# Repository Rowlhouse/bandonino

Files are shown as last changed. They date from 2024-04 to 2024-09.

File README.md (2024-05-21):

# Bandonino
Teensy powered midi "bandoneon", using mechanical key switches and a load-cell for bellows emulation.

It's powered, and outputs MIDI, over USB. I use my Android phone, running Audio Evolution Mobile, which does low latency MIDI conversion for real-time playing, as well as recording etc.

The bellows emulation uses a 3KG load cell, mounted using rubber grommets to allow for a little bit of movement (1cm or so).

Left/right sides emit midi on different channels so that they can be processed separately. It also outputs a third channel for a metronome.

# Goals

1. To help me learn the keyboard layout
2. To confirm my choice of layout (unisonoric - Peguri/Manoury layout)
3. To provide a learning experience that is at least somewhat "musically satisfying", in order to help me wait for the real thing to arrive.
4. To be a genuine, expressive, musical instrument, that goes beyond "press button, make sound", that might be interesting to use in situations where a real bandoneon isn't appropriate.

# Building 

More complete notes will follow, but for now, the layouts for the key switches are in the Construction directory.

The wiring is "inspired" by the KOOPInstruments projects - e.g. https://www.koopinstruments.com/instrument-projects/melodicade-mx so it uses a matrix (per side) of rows and columns of switches and diodes. Columns are activated in turn, and the buttons from each row are then read.

Most of the build was "improvised" (with 3mm and 6mm plywood sheets), once I'd designed the keyboard layout. The photos below document most of the process.

I was aiming for a "full size" instrument, though with angled ends so it didn't need to be as wide. I also wanted it to have some weight, so it would "open" the bellows to some degree automatically. It could be built much smaller and lighter.

The switches are mounted on plywood, with holes drilled in to (a) position them and (b) let the wires through. Then the matrix is made on the other side by soldering in a million diodes and little wire joiners.

The buttons are 3D printed, with graduated heights. Each button has a little flange. The buttons pass through holes in 2mm fibreglass plate (make the holes 1mm bigger than the buttons!). Now the plate has its height set so that it partially depresses the buttons. This reduces the travel needed to activate each one. 

## Note

If building again I would make two changes:

1. Reduce the button diameter by 0.5mm. This would have two benefits:
    1. increase the spacing between the holes in the plates (I used 2mm fibreglass), and reduce the risk of them breaking into each other.
    2. Make it possible to drill the holes in the plates with a standard size drill bit. 
2. Get a definitive layout from a friendly maker! I used photos to be as accurate as possible, but I think a few buttons are a few mm out.

# Electronics

The main items used are (the links aren't endorsements - just what I used/for reference!)

Teensy 4.1<br>
https://www.amazon.co.uk/dp/B0BHFBY68Q?psc=1&ref=ppx_yo2ov_dt_b_product_details

Gateron KS-9 RGB Mechanical MX Type Key Switch - Clear top (120 Pcs, Red)<br>
https://www.amazon.co.uk/gp/product/B07X3T14CV/ref=ppx_od_dt_b_asin_title_s00?ie=UTF8&psc=1<br>
Note that these need to have the 1mm plastic lugs removed from the sides as they have to be placed very close to each other!

Waveshare 1.5inch OLED Display Module 128x128 Pixels 16-bit Grey Level<br>
https://www.amazon.co.uk/dp/B079NNZ9V1?psc=1&ref=ppx_yo2ov_dt_b_product_details

Stemedu Load Cell 3KG Amplifier HX711<br>
https://www.amazon.co.uk/dp/B07L82YWPV?psc=1&ref=ppx_yo2ov_dt_b_product_details<br>
You need to switch (with delicate soldering!) the amp to use the 80Hz mode. I broke mine so used this load cell with a different HX711 amplifier:
https://www.amazon.co.uk/dp/B081JMSMXV

1N4148 Diodes<br>
https://www.amazon.co.uk/dp/B08TYC1ZRB?psc=1&ref=ppx_yo2ov_dt_b_product_details

KY-040 360 Degree Rotary Encoder<br>
https://www.amazon.co.uk/dp/B07B68H6R8?psc=1&ref=ppx_yo2ov_dt_b_product_details

# Inputs

| Input | Teensy Pin | Notes |
| ----- | --- | ----- |
| Left col 0 | 0 | |
| Left col 1 | 2 | |
| Left col 2 | 3 | |
| Left col 3 | 4 | |
| Left col 4 | 5 | |
| |  |  |
| Right col 0 | 6 | |
| Right col 1 | 7 | |
| Right col 2 | 8 | |
| Right col 3 | 9 | |
| Right col 4 | 20 | |
| Right col 6 | 21 | |
| |  |  |
| Left row 0 | 32 | |
| Left row 1 | 31 | |
| Left row 2 | 30 | |
| Left row 3 | 29 | |
| Left row 4 | 28 | |
| Left row 5 | 27 | |
| Left row 6 | 26 | |
| Left row 7 | 25 | |
| |  |  |
| Right row 0 | 33 | |
| Right row 1 | 34 | |
| Right row 2 | 35 | |
| Right row 3 | 36 | |
| Right row 4 | 37 | |
| Right row 5 | 38 | |
| Right row 6 | 39 | |
| Right row 7 | 40 | |
| Right row 8 | 41 | |
| |  |  |
| Load cell DT or DO/RX | 15 (A1) | From the strain guage to HX711 |
| Load cell SCK or CK/TX | 16 (A2) | red->out+, white->A- green->A+ black->GND |
| Load cell VCC | 5V | 5V seemed more reliable than 3.3 |
| |  |  |
| Rot encoder CLK | 22 | |
| Rot encoder DT | 23 (A9) | |
| Rot encoder SW | 17 | |
| Rot encoder + | 3.3V | |
| |  |  |
| OLED I2C CLK | 19 (SCL) | Set jumpers BS1 = BS2 = 1 to enable I2C |
| OLED I2C DIN | 18 (SDA) | |
| OLED I2C VCC | 3.3V | |

Experiments with a BME280 pressure sensor:
| BME280 CS | 10 | Using SPI |
| BME280 MISO | 12 | |
| BME280 SCK | 13 | |
| BME280 MOSI | 11 | |

# Software

I used a 128x128 display so that the menu system could include live note display - the left/right hands display on bass/treble clefs, or can be displayed as stacked notes. This has been really useful as I learn, and I'm pleased to say is becoming less useful as I improve!

The menu system itself is not written to be a standalone system, but could easily be adapted into a different project.

The main loop runs at a solid 80Hz, keeping up with the load cell/amplifier. When using note display, updating the display as notes change can drop a frame or so, but this is inaudible.

It supports writing/reading all the settings to an SD card - they can be saved explicitly, but also the current setting is saved automatically, and then restored when powering on.

# Libraries/building

I used/you'll need:

* https://www.mathertel.de/Arduino/RotaryEncoderLibrary.aspx
* https://github.com/bogde/HX711
* https://github.com/adafruit/Adafruit_SSD1327 v 1.0.4
* https://arduinojson.org/

I think all of these are available through Aruino Sketch. The full list of libraries is:

    RotaryEncoder at version 1.5.3 : [...]\Documents\Arduino\libraries\RotaryEncoder
    HX711 Arduino Library at version 0.7.5 : [...]\Documents\Arduino\libraries\HX711_Arduino_Library
    Adafruit SSD1327 at version 1.0.4 : [...]\Documents\Arduino\libraries\Adafruit_SSD1327
    Adafruit GFX Library at version 1.11.9 : [...]\Documents\Arduino\libraries\Adafruit_GFX_Library
    Adafruit BusIO at version 1.15.0 : [...]\Documents\Arduino\libraries\Adafruit_BusIO
    Wire at version 1.0 : [...]\AppData\Local\Arduino15\packages\teensy\hardware\avr\1.59.0\libraries\Wire
    SPI at version 1.0 : [...]\AppData\Local\Arduino15\packages\teensy\hardware\avr\1.59.0\libraries\SPI
    ArduinoJson at version 7.0.4 : [...]\Documents\Arduino\libraries\ArduinoJson
    SD at version 2.0.0 : [...]\AppData\Local\Arduino15\packages\teensy\hardware\avr\1.59.0\libraries\SD
    SdFat at version 2.1.2 : [...]\AppData\Local\Arduino15\packages\teensy\hardware\avr\1.59.0\libraries\SdFat

You'll need to select the board as Teensy 4.1 in Arduino Sketch, and USB type is Serial + MIDI

# Videos/photos

## Playing video demo

After learning to play for four weeks: https://youtu.be/XA5RVsj3e9U?si=FQ6Nt5ClDMPxDO7N

The audio is recorded on my phone as midi, and mixed there (so this is exactly what I hear if I play with headphones).

I've decided that the bellows emulation is reasonably effective (or at least, not totally misleading!) when "opening" the bellow - using instrument/arm weight, and modulating these without actively pulling. 

I don't think it emulates "closing" the bellows very well, so I've settled on only playing opening the bellows. This isn't ideal - but I think for proper bandoneon bellows technique, real bellows are needed!

## System demos

Newer:
https://youtu.be/Qa_-vbLSPUA?si=eyVYrDUC1PoKSc3D

Older:
https://youtu.be/M0wQ6heuBrk?si=m23eztmR4TV7uDbV

## Build photos etc

https://photos.app.goo.gl/t3dRVAY1abLQWBCG9

## Smaller set of photos/videos

https://photos.app.goo.gl/e3H986FrXZXdoZyL7

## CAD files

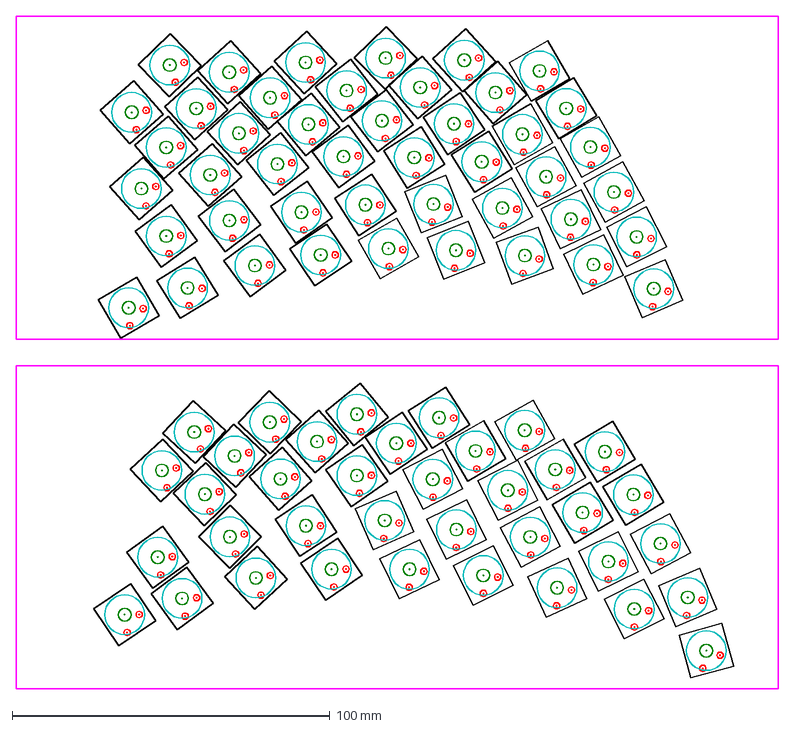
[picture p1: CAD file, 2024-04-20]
Construction/SwitchPlates.dxf
240.0 x 211.8 mm

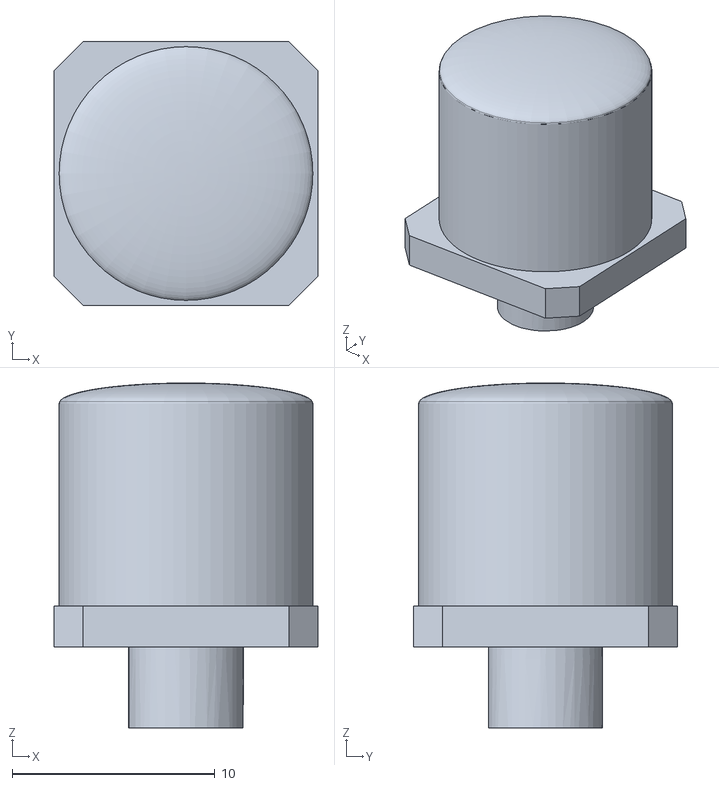
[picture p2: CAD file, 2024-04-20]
Construction/Bando Buttons (5).stl
13.0 x 13.0 x 17.0

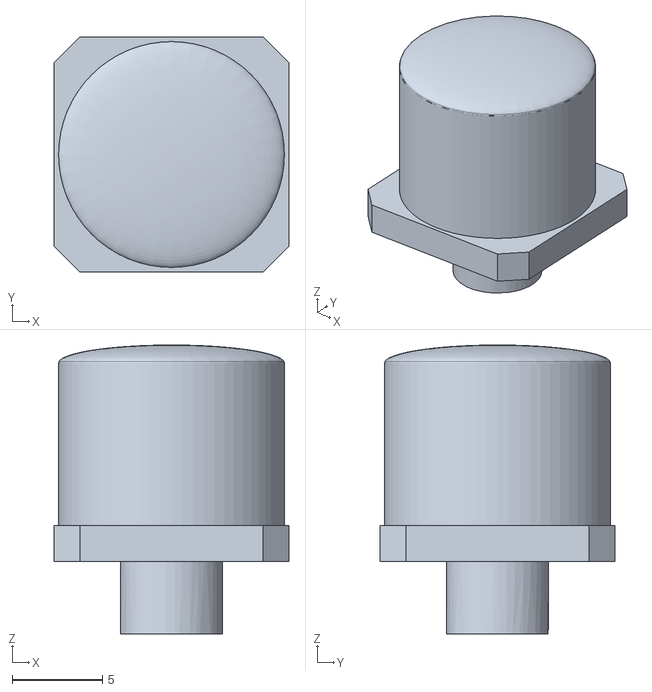
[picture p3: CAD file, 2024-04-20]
Construction/Bando Buttons (4).stl
13.0 x 13.0 x 16.0

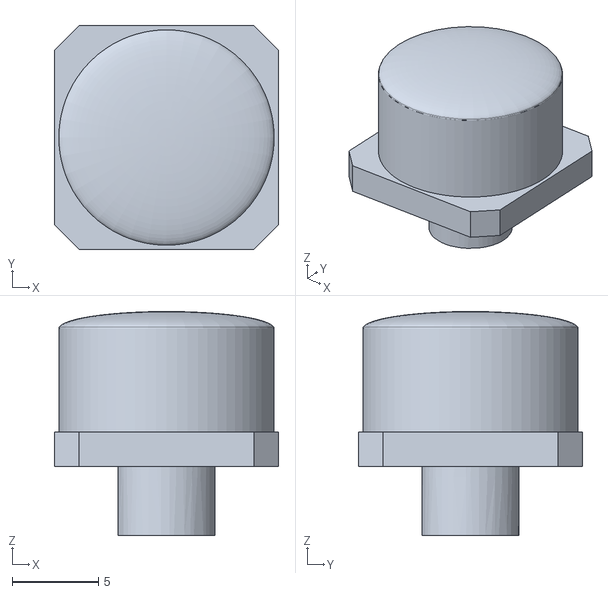
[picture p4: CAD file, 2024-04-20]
Construction/Bando Buttons (1).stl
13.0 x 13.0 x 13.0

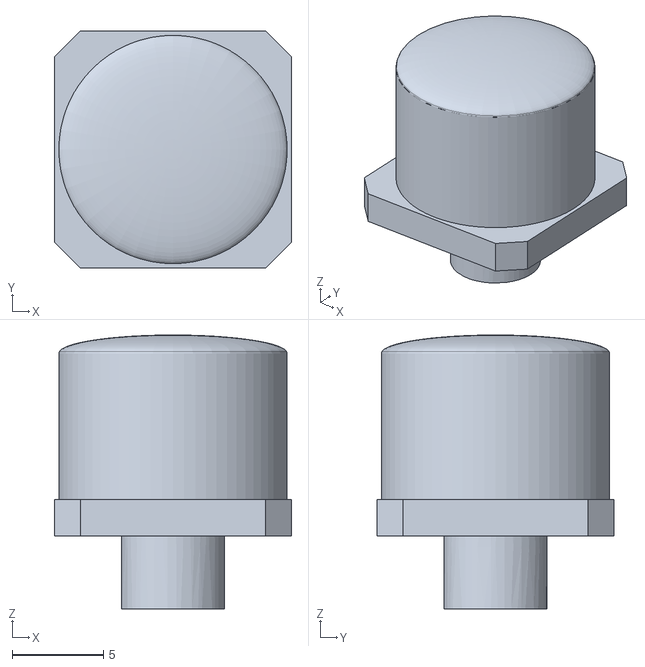
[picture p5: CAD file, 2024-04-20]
Construction/Bando Buttons (3).stl
13.0 x 13.0 x 15.0

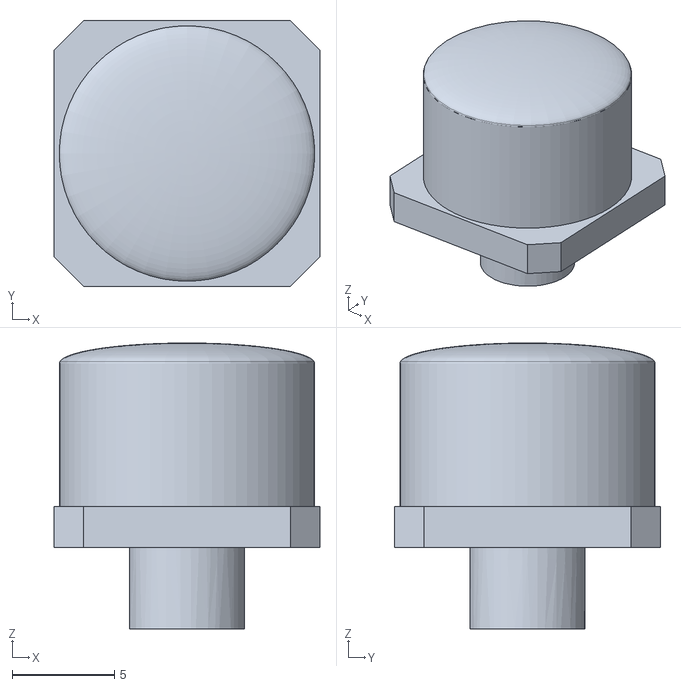
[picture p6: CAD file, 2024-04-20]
Construction/Bando Buttons (2).stl
13.0 x 13.0 x 14.0

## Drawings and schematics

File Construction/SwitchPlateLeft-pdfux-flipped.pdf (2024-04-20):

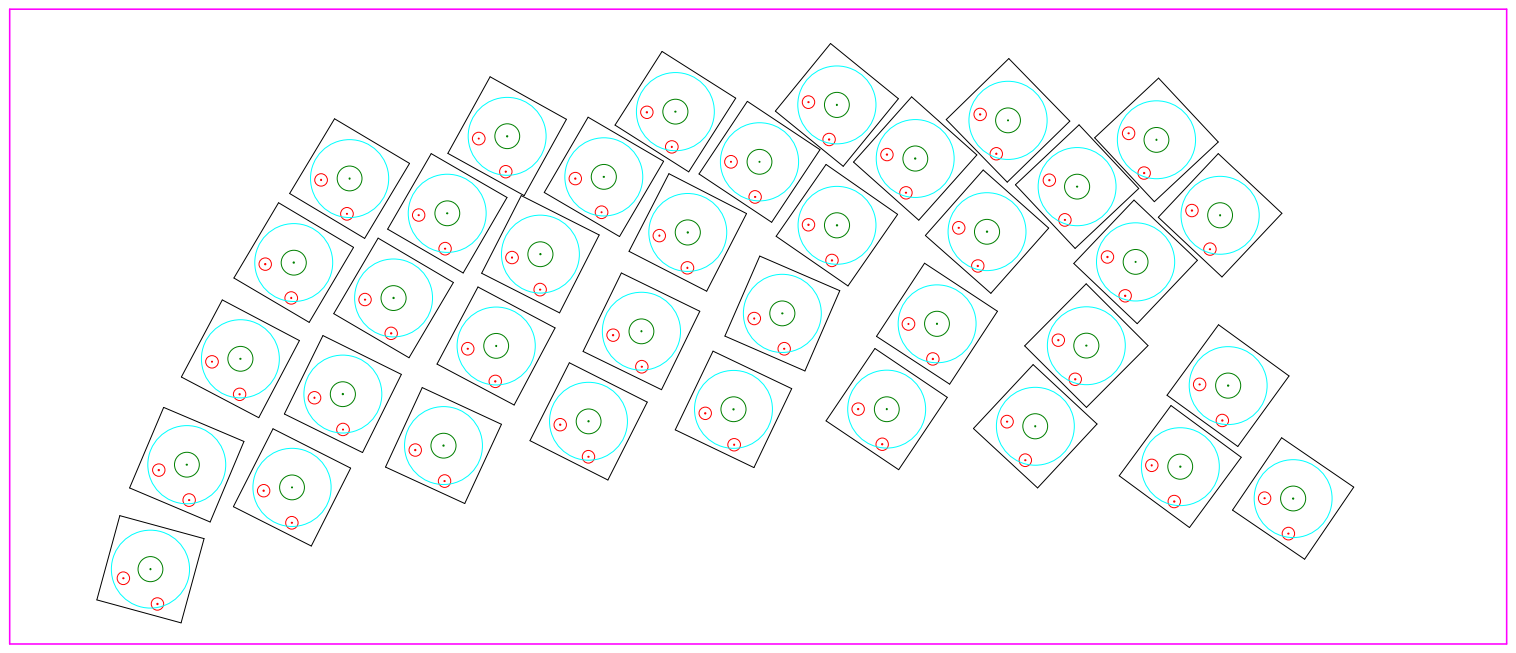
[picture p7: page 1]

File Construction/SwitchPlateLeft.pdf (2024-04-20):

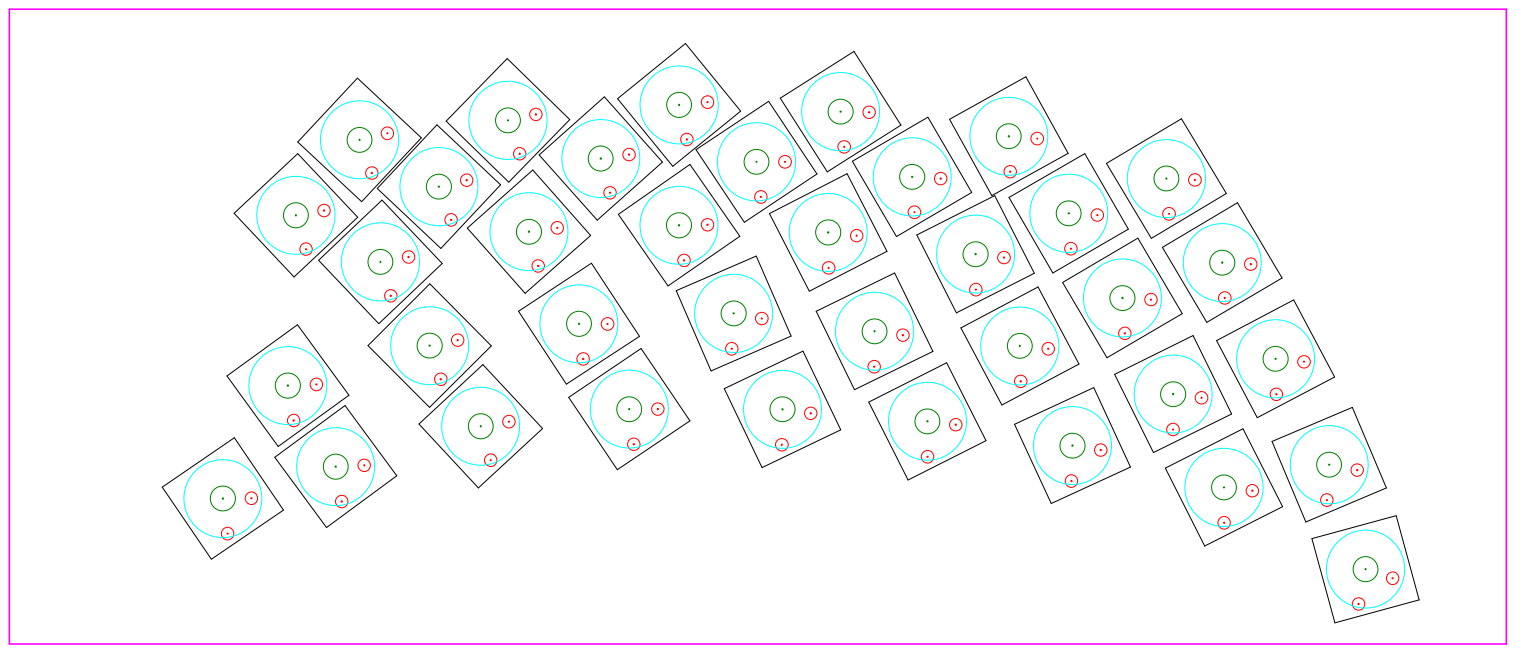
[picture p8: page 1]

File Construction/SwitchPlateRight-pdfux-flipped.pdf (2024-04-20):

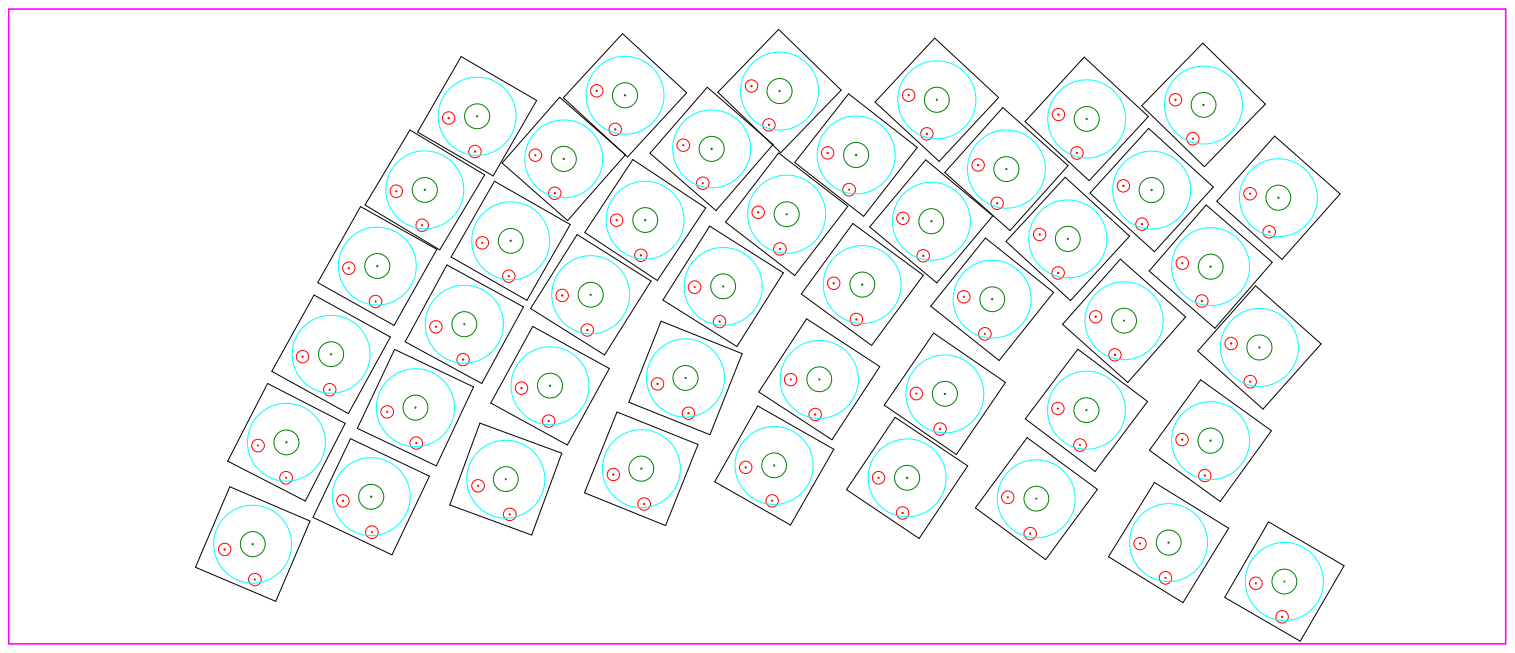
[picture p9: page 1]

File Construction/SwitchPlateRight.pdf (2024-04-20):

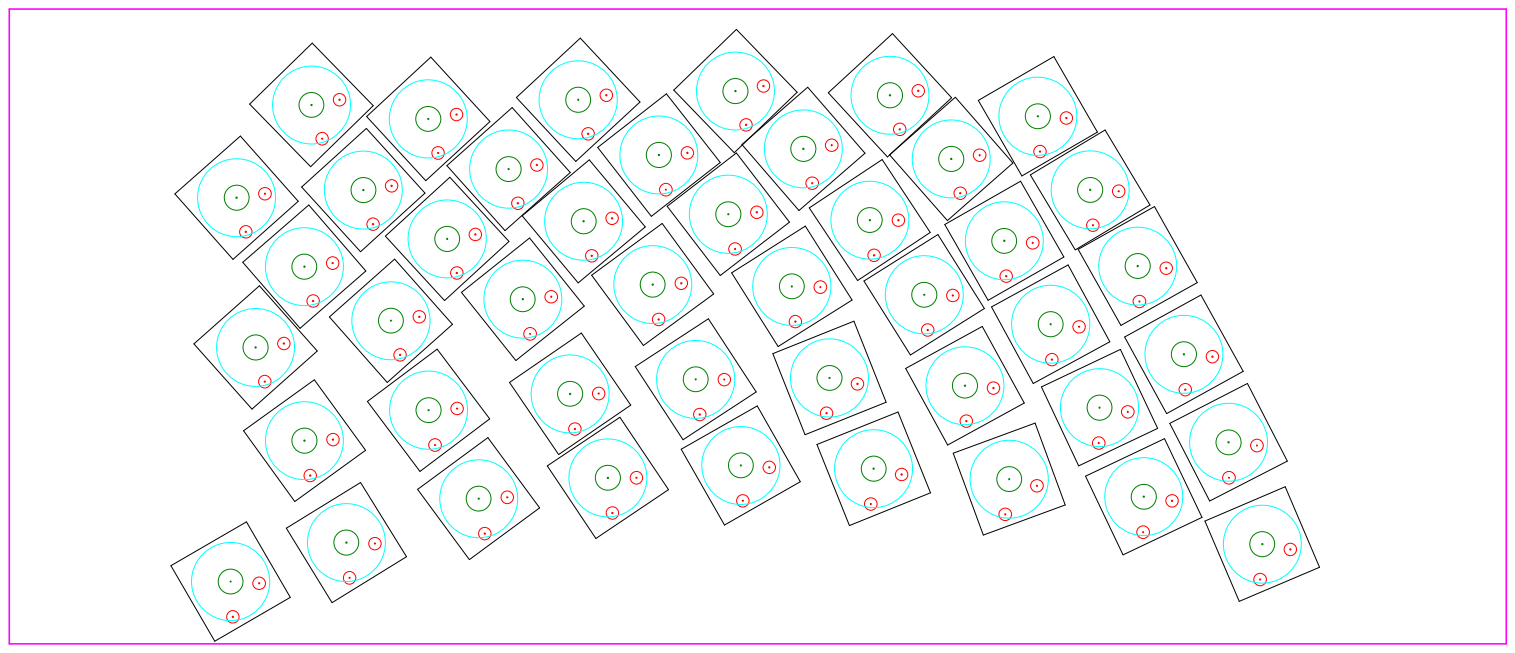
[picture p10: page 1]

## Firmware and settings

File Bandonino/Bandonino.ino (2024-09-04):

// https://www.mathertel.de/Arduino/RotaryEncoderLibrary.aspx
#include <RotaryEncoder.h>

#include "NoteNames.h"
#include "NoteLayouts.h"
#include "PinInputs.h"
#include "Settings.h"
#include "State.h"
#include "Menu.h"
#include "Metronome.h"
#include "Bellows.h"

// We don't have a State.cpp file, so put these here
BigState gBigState;
State gState;
State gPrevState;

// Config
// This is the wait (microseconds) between writing to the column and then reading from the rows.
const int sKeyReadDelayTime = 3;

bool runHardwareTest = false;
bool showKeys = false;
bool showBellows = false;
bool flashLED = true;
bool showRot = false;
bool showPlayingNotes = false;

//====================================================================================================
// Rotary encoder pins and library configuration
RotaryEncoder rotaryEncoder(ROTARY_PIN1, ROTARY_PIN2, RotaryEncoder::LatchMode::FOUR3);
// This interrupt routine will be called on any change of one of the input signals
void tickRotaryEncoderISR() {
  rotaryEncoder.tick();  // just call tick() to check the gState.
}

unsigned long lastHardwareTestPrintTime;  // Rate limit printing of hardwareTest() info to serial monitor

//====================================================================================================
void initInputPins(const byte pins[], byte pinCount, uint8_t mode) {
  for (int iPin = 0; iPin != pinCount; ++iPin)
    pinMode(pins[iPin], mode);
}

//====================================================================================================
void initKeys(byte activeKeys[], int keyCount) {
  for (int iKey = 0; iKey != keyCount; ++iKey)
    activeKeys[iKey] = 0;
}

// Used to force a periodic sync
const int SYNC_VALUE = -1234;

//====================================================================================================
inline int convertFractionToMidi(float frac) {
  return std::clamp((int)(128 * frac), 0, 127);
}

//====================================================================================================
inline int convertPercentToMidi(int percent) {
  return convertFractionToMidi(percent / 100.0f);
}

//====================================================================================================
void setup() {
  Serial.begin(38400);

  Serial.println("========= Starting Bandon.ino ==========");

  Serial.println("Loading gSettings from gSettings.json");
  if (!gSettings.readFromCard())
    Serial.println("Failed to load gSettings");

  syncNoteLayout();

  // Set pin modes - initially all LOW
  initInputPins(PinInputs::columnPinsLeft, PinInputs::columnCounts[LEFT], INPUT);
  initInputPins(PinInputs::columnPinsRight, PinInputs::columnCounts[RIGHT], INPUT);
  initInputPins(PinInputs::rowPinsLeft, PinInputs::rowCounts[LEFT], INPUT);
  initInputPins(PinInputs::rowPinsRight, PinInputs::rowCounts[RIGHT], INPUT);

  initKeys(gBigState.mActiveKeysLeft, PinInputs::keyCounts[LEFT]);
  initKeys(gBigState.mActiveKeysRight, PinInputs::keyCounts[RIGHT]);

  pinMode(LED_BUILTIN, OUTPUT);
  pinMode(ROTARY_ENCODER_BUTTON_PIN, INPUT_PULLUP);

  initBellows();

  attachInterrupt(digitalPinToInterrupt(ROTARY_PIN1), tickRotaryEncoderISR, CHANGE);
  attachInterrupt(digitalPinToInterrupt(ROTARY_PIN2), tickRotaryEncoderISR, CHANGE);

  initMenu();
}

//====================================================================================================
void readRotaryEncoder() {
  // Don't call rotaryEncoder.tick() because it's not safe - it's getting called in the interrupt
  gState.mRotaryEncoderPosition = rotaryEncoder.getPosition();
  gState.mRotaryEncoderPressed = !digitalRead(ROTARY_ENCODER_BUTTON_PIN);
}

//====================================================================================================
void loop() {
  gPrevState = gState;
  gState.mLoopStartTimeMillis = millis();

  // Periodically force the pan/volume to be sent, in case the receiving device wasn't plugged in when we last sent it!
  static uint32_t lastMidiSyncTime = 0;
  if (gState.mLoopStartTimeMillis > lastMidiSyncTime + 1000) {
    for (int side = 0; side != 2; ++side) {
      gPrevState.mMidiPans[side] = SYNC_VALUE;
      gPrevState.mMidiVolumes[side] = SYNC_VALUE;
      gPrevState.mMidiInstruments[side] = SYNC_VALUE;
    }
    lastMidiSyncTime = gState.mLoopStartTimeMillis;
  }

  // Inputs needs to be processed before the menus
  readRotaryEncoder();

  readAllKeys();

  updateMenu();

  syncNoteLayout();

  updateVolumes();

  updateMidi();

  playAllKeys();

  usbMIDI.send_now();

  updateMetronome();

  if (runHardwareTest)
    hardwareTest();
}

//====================================================================================================
void convertBalanceToLevels(int balance, int levels[2]) {
  if (balance >= 0) {
    levels[LEFT] = 100 - balance;
    levels[RIGHT] = 100;
  } else {
    levels[LEFT] = 100;
    levels[RIGHT] = 100 + balance;
  }
}

//====================================================================================================
void updateVolumes() {
  if (gSettings.forceBellows == 0) {
    updateBellows();

    // Send the pressure to modulate volume
    gState.mAbsPressure = std::min(fabsf(gState.mPressure), 1.0f);  //Absolute Channel Pressure

    float deadzone = gSettings.deadzone / 100.0f;
    float cleanAbsPressure = std::max((gState.mAbsPressure - deadzone) / (1.0f - deadzone), 0.0f);

    float a25 = gSettings.attack25 / 100.0f;
    float a50 = gSettings.attack50 / 100.0f;
    float a75 = gSettings.attack75 / 100.0f;

    if (cleanAbsPressure < 0.25f) {
      gState.mModifiedPressure = (cleanAbsPressure * a25) / 0.25f;
    } else if (cleanAbsPressure < 0.5f) {
      gState.mModifiedPressure = a25 + ((cleanAbsPressure - 0.25f) * (a50 - a25)) / 0.25f;
    } else if (cleanAbsPressure < 0.75f) {
      gState.mModifiedPressure = a50 + ((cleanAbsPressure - 0.5f) * (a75 - a50)) / 0.25f;
    } else {
      gState.mModifiedPressure = a75 + ((cleanAbsPressure - 0.75f) * (1.0f - a75)) / 0.25f;
    }

    // Handle bellows reversals
    if (gState.mModifiedPressure == 0) {  //Bellows stopped
      gState.mBellowsState = BELLOWS_STATE_STATIONARY;
      if (gPrevState.mModifiedPressure != 0) {  //Bellows were not previously stopped
        stopAllNotes();                 //All Notes Off
      }
    } else {                       //Bellows not stopped
      if (gState.mPressure < 0) {  //Pull
        gState.mBellowsState = BELLOWS_STATE_OPENING;
        if (gPrevState.mPressure >= 0) {  //Pull and Previously Push or stopped
          stopAllNotes();                 //All Notes Off
        }
      }
      if (gState.mPressure > 0) {  //Push
        gState.mBellowsState = BELLOWS_STATE_CLOSING;
        if (gPrevState.mPressure <= 0) {  //Push and Previously Pull or stopped
          stopAllNotes();                 //All Notes Off
        }
      }
    }

    // If the quantized volume is zero, force that to show as no bellows movement
    if (gState.mMidiVolumes[LEFT] == 0 && gState.mMidiVolumes[RIGHT] == 0)
      gState.mBellowsState = BELLOWS_STATE_STATIONARY;

  } else {
    gState.mModifiedPressure = 1.0f;
    gState.mAbsPressure = 1.0f;

    gState.mBellowsState = gSettings.forceBellows == 1 ? BELLOWS_STATE_OPENING : BELLOWS_STATE_CLOSING;
  }

  int levels[2];
  convertBalanceToLevels(gSettings.balance, levels);

  for (int side = 0; side != 2; ++side) {
    if (gSettings.expressions[side] == EXPRESSION_VOLUME) {
      float volume = gState.mModifiedPressure * levels[side] / 100.0f;
      gState.mMidiVolumes[side] = std::min((int)(128 * volume), 127);
    } else {
      gState.mMidiVolumes[side] = 127;
    }

    if (gState.mMidiVolumes[side] != gPrevState.mMidiVolumes[side])
      usbMIDI.sendControlChange(0x07, gState.mMidiVolumes[side], gSettings.midiChannels[side]);
  }
}

//====================================================================================================
void updateMidi() {
  // MIDI Controllers should discard incoming MIDI messages.
  while (usbMIDI.read()) {
    // read & ignore incoming messages
  }

  int pans[2] = { -gSettings.stereo, gSettings.stereo };

  // Pan control (coarse). 0 is supposedly hard left, 64 center, 127 is hard right
  // That's weird, as it means there's a different range on left and right!
  for (int side = 0; side != 2; ++side) {
    gState.mMidiPans[side] = 64 + (pans[side] * 63) / 100;
    if (gState.mMidiPans[side] != gPrevState.mMidiPans[side]) {
      usbMIDI.sendControlChange(10, gState.mMidiPans[side], gSettings.midiChannels[side]);
      if (gPrevState.mMidiPans[side] != SYNC_VALUE)
        Serial.printf("Pan %d = %d\n", side, gState.mMidiPans[side]);
    }

    gState.mMidiInstruments[side] = gSettings.midiInstruments[side];
    if (gState.mMidiInstruments[side] != gPrevState.mMidiInstruments[side]) {
      if (gState.mMidiInstruments[side] != -1)
        usbMIDI.sendProgramChange(gState.mMidiInstruments[side], gSettings.midiChannels[side]);
    }
  }
}

//====================================================================================================
void playNote(int midiNote, byte velocity, const int midiChannel, byte playingNotes[]) {
  if (midiNote > 0 && midiNote <= 127) {
    usbMIDI.sendNoteOn(midiNote, velocity, midiChannel);
    if (velocity > 0) {
      ++playingNotes[midiNote];
    }
  }
}

//====================================================================================================
void stopNote(int midiNote, byte velocity, const int midiChannel, byte playingNotes[]) {
  if (midiNote > 0 && midiNote <= 127) {
    if (playingNotes[midiNote] > 0)
      --playingNotes[midiNote];
    if (playingNotes[midiNote] <= 0)
      usbMIDI.sendNoteOff(midiNote, velocity, midiChannel);
  }
}

//====================================================================================================
void stopAllNotes() {
  // Serial.println("All notes off");
  for (int side = 0; side != 2; ++side) {
    usbMIDI.sendControlChange(0x7B, 0, gSettings.midiChannels[side]);  // 123
    for (int iKey = 0; iKey != PinInputs::keyCounts[side]; ++iKey)
      gBigState.previousActiveKeys(side)[iKey] = 0;
    for (int midi = gSettings.midiMin; midi <= gSettings.midiMax; ++midi) {
      gBigState.mPlayingNotes[side][midi] = 0;
    }
  }
}

//====================================================================================================
int getMidiNoteForKey(int iKey, const byte* noteLayoutOpen, const byte* noteLayoutClose, int transpose) {
  if (gState.mBellowsState == BELLOWS_STATE_STATIONARY)
    return -1;
  int midiNote = gState.mBellowsState == BELLOWS_STATE_OPENING ? noteLayoutOpen[iKey] : noteLayoutClose[iKey];
  if (midiNote > 0 && midiNote <= 127) {
    midiNote += transpose;
    if (midiNote > 0 && midiNote <= 127) {
      return midiNote;
    }
  }
  return -1;
}

//====================================================================================================
void playKeys(
  const byte activeKeys[], byte previousActiveKeys[], const int keyCount, const int midiChannel,
  const byte* noteLayoutOpen, const byte* noteLayoutClose, byte playingNotes[],
  int velocity, int offVelocity, int transpose) {
  for (int iKey = 0; iKey != keyCount; ++iKey) {
    if (activeKeys[iKey] && !previousActiveKeys[iKey]) {
      if (gState.mBellowsState != BELLOWS_STATE_STATIONARY) {
        // Start playing, but only if there is some bellows action.
        playNote(getMidiNoteForKey(iKey, noteLayoutOpen, noteLayoutClose, transpose), velocity, midiChannel, playingNotes);
        // Only update previous activity if there is bellows motion - otherwise pressing a key with
        // the bellows stationary can result in losing the note.
        previousActiveKeys[iKey] = activeKeys[iKey];
      }
    } else if (!activeKeys[iKey] && previousActiveKeys[iKey]) {
      // Stop playing
      stopNote(getMidiNoteForKey(iKey, noteLayoutOpen, noteLayoutClose, transpose), offVelocity, midiChannel, playingNotes);
      previousActiveKeys[iKey] = activeKeys[iKey];
    }
  }
}

//====================================================================================================
int getVelocity(int side) {
  if (gSettings.expressions[side] == EXPRESSION_VOLUME)
    return gSettings.maxVelocity[side];
  int levels[2];
  convertBalanceToLevels(gSettings.balance, levels);
  return convertFractionToMidi(
    gState.mModifiedPressure * (levels[side] / 100.0f) * (gSettings.maxVelocity[side] / 127.0f));
}

//====================================================================================================
void playAllKeys() {
  for (int side = 0; side != 2; ++side) {
    int velocity = getVelocity(side);
    int offVelocity = gSettings.noteOffVelocity[side];
    int transpose = gSettings.transpose + gSettings.octave[side] * 12;
    playKeys(gBigState.activeKeys(side), gBigState.previousActiveKeys(side),
             PinInputs::keyCounts[side], gSettings.midiChannels[side],
             gBigState.mNoteLayout.open(side), gBigState.mNoteLayout.close(side),
             gBigState.mPlayingNotes[side],
             velocity, offVelocity, transpose);
  }
}

//====================================================================================================
void readKeys(const byte rowPins[], const byte columnPins[], byte activeKeys[], uint32_t activeKeysTime[], int rowCount, int columnCount) {
  uint32_t currentMillis = millis();

  for (int iColumn = 0; iColumn != columnCount; ++iColumn) {
    byte columnPin = columnPins[iColumn];

    pinMode(columnPin, OUTPUT);
    digitalWrite(columnPin, LOW);

    for (int iRow = 0; iRow != rowCount; ++iRow) {
      byte rowPin = rowPins[iRow];
      pinMode(rowPin, INPUT_PULLUP);

      byte iKey = toKeyIndex(iRow, iColumn, rowCount, columnCount);

      if (sKeyReadDelayTime > 0)
        delayMicroseconds(sKeyReadDelayTime);

      byte keyState = !digitalRead(rowPin);

      if (keyState == HIGH) {
        activeKeys[iKey] = 1;
        activeKeysTime[iKey] = currentMillis;
      }

      if (keyState == LOW && int(currentMillis - activeKeysTime[iKey]) >= gSettings.debounceTime) {
        activeKeys[iKey] = 0;
      }
      pinMode(rowPin, INPUT);
    }
    pinMode(columnPin, INPUT);
  }
}

//====================================================================================================
void readAllKeys() {
  for (int side = 0; side != 2; ++side) {
    readKeys(
      PinInputs::rowPins(side), PinInputs::columnPins(side), gBigState.activeKeys(side),
      gBigState.activeKeysTimes(side), PinInputs::rowCounts[side], PinInputs::columnCounts[side]);
  }
}

//====================================================================================================
void hardwareTest() {
  static byte counter = 0;

  // Interval between outputing info. -ve early outs.
  int interval = 250;

  if (showRot) {
    if (gPrevState.mRotaryEncoderPosition != gState.mRotaryEncoderPosition) {
      Serial.print("rotary encoder pos:");
      Serial.print(gState.mRotaryEncoderPosition);
      Serial.print(" dir:");
      Serial.println((int)(rotaryEncoder.getDirection()));
    }
  }

  if (flashLED) {
    // This can be used to measure the tick rate - since it cycles every 256 ticks
    analogWrite(LED_BUILTIN, counter += 1);
  }

  if (millis() < lastHardwareTestPrintTime + interval)
    return;

  lastHardwareTestPrintTime = millis();

  if (showBellows) {
    Serial.println("Bellows");
    Serial.println(gState.mPressure);
    Serial.println(gState.mModifiedPressure);
    Serial.println(gState.mBellowsState);
  }

  if (showKeys) {
    Serial.println("Keys left");
    for (int j = 0; j != PinInputs::columnCounts[LEFT]; ++j) {
      for (int i = 0; i < PinInputs::rowCounts[LEFT]; i++) {
        int iKey = INDEX_LEFT(i, j);
        Serial.print(gBigState.mActiveKeysLeft[iKey]);
        Serial.print(" (");
        Serial.print(gState.mBellowsState == BELLOWS_STATE_OPENING ? gBigState.mNoteLayout.mLeftOpen[iKey] : gBigState.mNoteLayout.mLeftClose[iKey]);
        Serial.print(")");
        Serial.print("\t");
      }
      Serial.println();
    }
    Serial.println("Keys right");
    for (int j = 0; j != PinInputs::columnCounts[RIGHT]; ++j) {
      for (int i = 0; i < PinInputs::rowCounts[RIGHT]; i++) {
        int iKey = INDEX_RIGHT(i, j);
        Serial.print(gBigState.mActiveKeysRight[iKey]);
        Serial.print(" (");
        Serial.print(gState.mBellowsState == BELLOWS_STATE_OPENING ? gBigState.mNoteLayout.mRightOpen[iKey] : gBigState.mNoteLayout.mRightClose[iKey]);
        Serial.print(")");
        Serial.print("\t");
      }
      Serial.println();
    }
    Serial.println();
  }

  if (showPlayingNotes) {
    Serial.print("Playing notes left: ");
    for (int i = gSettings.midiMin; i <= gSettings.midiMax; ++i) {
      if (gBigState.mPlayingNotes[LEFT][i]) {
        NoteInfo noteInfo = getNoteInfo(
          i, CLEF_TREBLE, gSettings.accidentalPreference, gSettings.accidentalKey);
        Serial.printf("%s ", noteInfo.mName);
      }
    }
    Serial.println();
    Serial.print("Playing notes right: ");
    for (int i = gSettings.midiMin; i <= gSettings.midiMax; ++i) {
      if (gBigState.mPlayingNotes[RIGHT][i]) {
        NoteInfo noteInfo = getNoteInfo(
          i, CLEF_TREBLE, gSettings.accidentalPreference, gSettings.accidentalKey);
        Serial.printf("%s ", noteInfo.mName);
      }
      Serial.println();
    }
  }

  // Serial.println();
  // Serial.print("Rotary Enc Pos: ");
  // Serial.print(rotaryEncoderPosition);
  // Serial.print("\t");
  // Serial.print("Rotary Enc Button: ");
  // Serial.print(rotaryEncoderButton);
  // Serial.print("\t");
  // Serial.print("Top Pot Val: ");
  // Serial.print(topPotValue);
  // Serial.print("\t");
  // Serial.print("Bottom Pot Val: ");
  // Serial.print(bottomPotValue);
  // Serial.print("\t");
  // Serial.print("Foot Switch: ");
  // Serial.print(footPedalButton);
  // Serial.println();
}

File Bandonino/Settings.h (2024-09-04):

#ifndef SETTINGS_H
#define SETTINGS_H

#include "NoteLayouts.h"
#include "NoteNames.h"

#include <stdint.h>
#include <limits.h>

enum Expression {
  EXPRESSION_VOLUME,
  EXPRESSION_VELOCITY,
  EXPRESSION_NUM
};
extern const char* gExpressionNames[];

enum NoteDisplay {
  NOTE_DISPLAY_STACKED,
  NOTE_DISPLAY_PLACED,
  NOTE_DISPLAY_NUM
};
extern const char* gNoteDisplayNames[];

struct Settings {
  int slot;  // settings slot - e.g. 0 to 9
  int noteLayout = NOTELAYOUTTYPE_MANOURY2;
  int forceBellows = 0;    // 1 means use opening. -1 means use closing. 0 means use the pressure sensor
  long zeroLoadReading = LONG_MAX ; // Reasonable LONG_MAX means to measure
  int  zeroLoadOffset = 0; // Will be applied and then immediately zeroed
  int pressureGain = 100;  // Treat as percentage - but it can go above 100
  int expressions[2] = { EXPRESSION_VOLUME, EXPRESSION_VOLUME };
  int maxVelocity[2] = { 126, 126 };
  int noteOffVelocity[2] = { 64, 64 };
  int octave[2] = { 0, 0 };  // up/down in octaves, per side
  int transpose = 0;         // in semitones

  int debounceTime = 0;  // milliseconds. Turns out not to be very helpful

  int midiChannels[2] = { 1, 2 };
  int midiInstruments[2] = { -1, -1 };  // -1 means don't send - let the playback system decide

  bool metronomeEnabled = false;
  int metronomeBeatsPerMinute = 100;
  int metronomeBeatsPerBar = 4;
  int metronomeVolume = 50;
  int metronomeMidiNotePrimary = 60;
  int metronomeMidiNoteSecondary = 80;
  int metronomeMidiChannel = 3;
  int metronomeMidiInstrument = 115;  // Appears to be woodblock
  bool metronomeLED = true;

  // percentages between -100 and 100
  // int pans[2] = { -25, 25 };

  // 0 is mono. 100 is full left/right. -100 is right/left
  int stereo = 50;
  // 0 is equal treble/bass. 100 is treble only. -100 is bass only
  int balance = 0;

  // Percentages between 0 and 100
  // int levels[2] = { 100, 100 };

  int showFPS = 0;
  int menuBrightness = 12;  // 0 to 0xf
  int noteDisplay = NOTE_DISPLAY_STACKED;
  int accidentalPreference = ACCIDENTAL_PREFERENCE_KEY;
  int accidentalKey = KEY_OFFSET;

  int menuPageIndex = 2;
  bool menuDisplayEnabled = true;

  // Shape the pressure response using attack params. As percentages
  int deadzone = 10;  // pressure is rescaled to remove this %
  int attack25 = 25;  // output when pressure = 25%
  int attack50 = 55;  // output when pressure = 50%
  int attack75 = 75;  // output when pressure = 75%

  // Things below here are updated automatically
  uint8_t midiMin = 0;
  uint8_t midiMax = 127;

  // Call this to limit the range of midi notes we traverse after changing the layout
  void updateMIDIRange();

  // Sets everything to defaults EXCEPT the zero load reading is preserved
  void reset();

  bool writeToCard(const char* filename = "gSettings.json");
  bool readFromCard(const char* filename = "gSettings.json");
};

extern Settings gSettings;

#endif

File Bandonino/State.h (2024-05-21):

#ifndef STATE_H
#define STATE_H

#include "NoteLayouts.h"
#include "PinInputs.h"

struct Settings;

enum BellowsState {
  BELLOWS_STATE_CLOSING = -1,
  BELLOWS_STATE_STATIONARY = 0,
  BELLOWS_STATE_OPENING = 1
};

// Big state - don't copy
struct BigState {
  // The actual note layout
  NoteLayout mNoteLayout;

  uint8_t mActiveKeysLeft[PinInputs::keyCounts[LEFT]];
  uint8_t mActiveKeysRight[PinInputs::keyCounts[RIGHT]];
  uint8_t* activeKeys(int side) {
    return side ? mActiveKeysRight : mActiveKeysLeft;
  };

  uint8_t mPreviousActiveKeysLeft[PinInputs::keyCounts[LEFT]];
  uint8_t mPreviousActiveKeysRight[PinInputs::keyCounts[RIGHT]];
  uint8_t* previousActiveKeys(int side) {
    return side ? mPreviousActiveKeysRight : mPreviousActiveKeysLeft;
  };

  // This is set to the current time (ms) when the key is being pressed - so it's
  // possible to tell how long ago it has been since the key was released.
  uint32_t mActiveKeysTimeLeft[PinInputs::keyCounts[LEFT]];
  uint32_t mActiveKeysTimeRight[PinInputs::keyCounts[RIGHT]];
  uint32_t* activeKeysTimes(int side) {
    return side ? mActiveKeysTimeRight : mActiveKeysTimeLeft;
  };

  // Indexed by midi. These a reference counted (so if multiple buttons activate the note, then that is tracked)
  uint8_t mPlayingNotes[2][127];
};

// State can be copied and checked for changes
struct State {
  BellowsState mBellowsState = BELLOWS_STATE_STATIONARY;

  // Raw load cell data
  long mLoadReading;

  // Pressures - converted using the gain
  float mPressure = 0.0f;
  float mAbsPressure = 0.0f;       // clamped to 0 and 1
  float mModifiedPressure = 0.0f;  // clamped to 0 and 1

  int mMidiPans[2] = { -1, -1 };
  int mMidiVolumes[2] = { -1, -1 };  // scaled to 0-127
  int mMidiInstruments[2] = { 1, 1 };

  int mRotaryEncoderPosition = 0;
  bool mRotaryEncoderPressed = false;
  uint32_t mLoopStartTimeMillis = 0;

  void readPressure();
};

extern BigState gBigState;
extern State gState;
extern State gPrevState;

#endif

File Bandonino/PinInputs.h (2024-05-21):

#ifndef PININPUTS_H
#define PININPUTS_H

#include <stdint.h>

namespace PinInputs {
static constexpr int rowCounts[2] = { 8, 8 };
static constexpr int columnCounts[2] = { 5, 6 };

static constexpr uint8_t columnPinsLeft[columnCounts[0]] = { 5, 4, 3, 2, 0 };
static constexpr uint8_t columnPinsRight[columnCounts[1]] = { 21, 20, 9, 8, 7, 6 };
static constexpr uint8_t rowPinsLeft[rowCounts[0]] = { 32, 31, 30, 29, 28, 27, 26, 25 };
static constexpr uint8_t rowPinsRight[rowCounts[1]] = { 40, 39, 38, 37, 36, 35, 34, 33 };

inline const uint8_t* columnPins(int side) {
  return side ? columnPinsRight : columnPinsLeft;
}
inline const uint8_t* rowPins(int side) {
  return side ? rowPinsRight : rowPinsLeft;
}

static constexpr int keyCounts[2] = { rowCounts[0] * columnCounts[0], rowCounts[1] * columnCounts[1] };
};

inline int toKeyIndex(int row, int column, int rowCount, int columnCount) {
  return (column * rowCount) + row;
}
#define INDEX_LEFT(row, column) toKeyIndex(row, column, PinInputs::rowCounts[0], PinInputs::columnCounts[0])
#define INDEX_RIGHT(row, column) toKeyIndex(row, column, PinInputs::rowCounts[1], PinInputs::columnCounts[1])

#define LOADCELL_DOUT_PIN 15
#define LOADCELL_SCK_PIN 16

// Digital input pins
#define ROTARY_ENCODER_BUTTON_PIN 17
#define ROTARY_PIN1 A9
#define ROTARY_PIN2 A8


#endif

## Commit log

2024-03-27 Use the correct sketch name
    [Settings.h]
2024-03-28 Switch to a faster OLED library.
2024-03-31 Flip the pin orders so the layouts in code match the actual keyboard layout
    [Menu.cpp, PinInputs.h]
2024-03-31 Tweaks prior to trying switch to a 1327 display
2024-04-01 Switch to 1327 based OLED for a 128x128 display. Use ISR for rotary encoder
2024-04-06 Option for breath or velocity expression
2024-04-10 Save the current menu page and display state
2024-04-12 Default metronome to 50%. Expose max midi velocity in menu.
2024-04-16 Fix crash caused by the bellows state change. Fix situations where notes get lost if played with the bellows stationary
    [State.h]
2024-04-20 Add construction files
    [Bando Buttons (1).stl, Bando Buttons (2).stl, Bando Buttons (3).stl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]
2024-04-22 Add option for note off velocity. Remove status menu. Move the Metronome to the beginning.
2024-04-27 Metronome flashes the LED
2024-05-07 Switch to stereo/balance controls. Allow -1 to not set the midi instrument. Make presets for my sound font (0 = bandoneon, 1 = concertina, 2 = piano)
2024-05-21 Makes the zero bellows reading a setting so it is preserved. Updates the pin inputs since they've been tweaked
2024-06-04 Preserve bellows/zero load reading when switching instrument setups
2024-09-04 Support for bellows deadzone. Also fix the bug where sometimes notes would not stop.
    [Bandonino.ino, Menu.cpp, Settings.cpp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]
